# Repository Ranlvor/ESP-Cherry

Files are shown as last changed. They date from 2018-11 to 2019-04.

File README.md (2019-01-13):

# ESP-Cherry
Little board that connects 4 Cherry Switches and 4 LEDs to a Wemos D1 Mini Board

# Folder Structure:
* ESP-Cerry: KiCad Project of the Board
* gehaeuse: OpenSCAD Project for a 3D printed casing

# Parts
* U1: Wemos D1 Mini
* Switches SW1, SW2, SW3, SW4: CHERRY MX-Switches, choose to your liking
* Resistors R1, R2: Pull-Up-Resistors for SW3 and SW4, 1kΩ - 100kΩ should be fine
* LEDs D1, D2, D3, D4: LEDs to iluminate the Keykaps, choose to your liking.  Use LEDs which fit your switches. The switches I used fit 3mm LED's but some do not
* Resistors R3, R4, R5, R6: protective resistors for LEDs D1, D2, D3, D4: choose whatever fits your LEDs to be powered from 3.3V.

## Optional Parts:
* Add R7 = 4.7kΩ and U2 = DS18B20 for temperature mesurement

# Other
* Power the Wemos D1 via USB, it powers the rest of the board (or solder 3.3V or 5V directly to the Wemos)
* Mounting Holes fit M3 screws
* Mounting Holes Positions in mm from the lower left corner of the board:
  * 5.08, 20.32
  * 5.08, 40.64
  * 5.08, 58.42
  * 5.08, 78.74
  * 52.07, 7.62
  * 52.07, 78.74

# Software
* Use whatever can control IO pins
* I use Tasmota-Firmware with the following IO-settings:
  * Modul type: 18 Generic
  * D3 GPIO0: 15 Switch7
  * D4 GPIO2: 16 Switch8
  * D2 GPIO4: 14 Switch6
  * D1 GPIO5: 13 Switch5
  * D6 GPIO12: 22 Relay2
  * D7 GPIO13: 21 Relay1
  * D5 GPIO14: 23 Relay3
  * D0 GPIO16: 24 Relay4
  * otherwise: 00 None

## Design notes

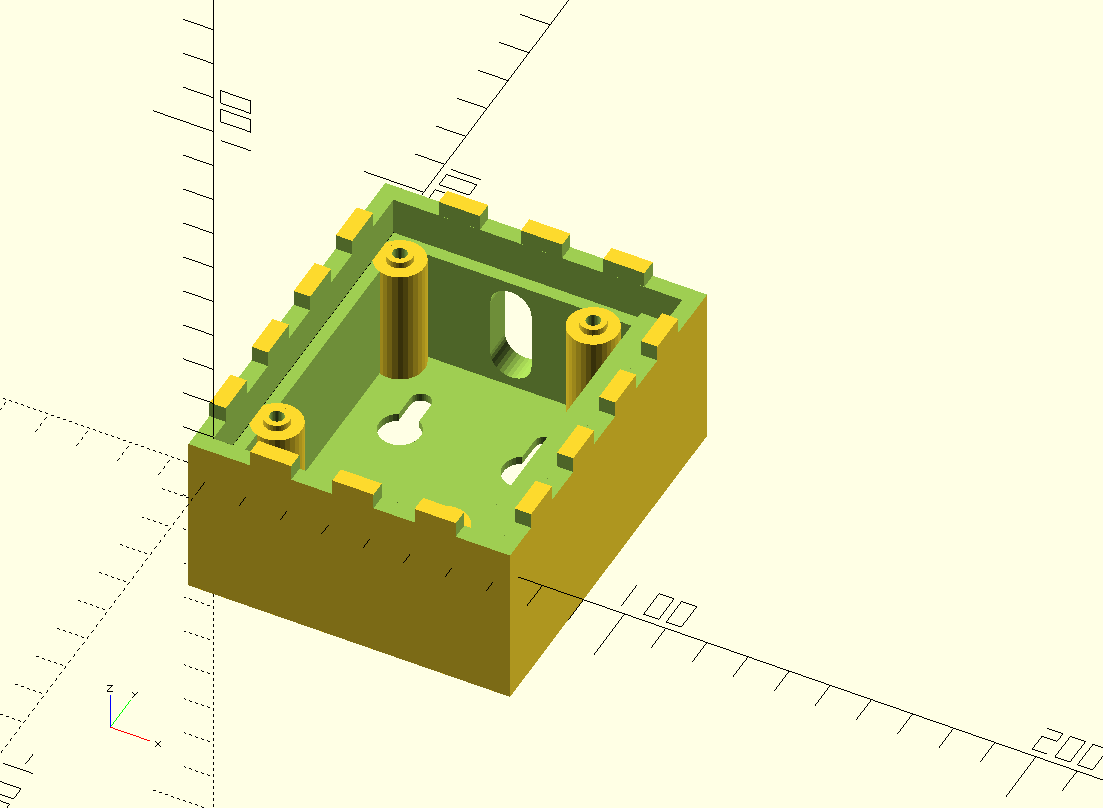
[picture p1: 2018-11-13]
gehaeuse/render.png

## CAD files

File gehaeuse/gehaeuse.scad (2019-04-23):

$fn = 32;
//unit = mm
boardTolerance = 0.5;
boardX = 59.69 + boardTolerance;
boardY = 85.09 + boardTolerance;
boardZ = 1.6;
overhang = 3;
delta = 0.02;
floorThickness = 2;
xExtraSpace = 10;
buttonToUserPannel = 12; //distance between top of board to top of gehaeuse
deckelDicke = 4;
wallUpper = deckelDicke;
//clearence = 30;
clearence = 25;

mountingPillarThickness = 6;
mountingNutDiameter = 4;
mountingNutScrewDiameter = 3;
renderMode = 1; //1 = 3D lower, 2 = 2D upper, 3 = 2D upper outline, 4 = 2D upper text
//color([0,1,0]) cube([boardX-delta, boardY-delta, boardZ-delta]);

tolerance = 0; //faster rendering
//tolerance = 2; //simpler testing
//tolerance = 0.3; //for final render

usbHoleThickness = 10;
usbHoleLength = 12;

mountingScrewDiameter = 6;
mountingScewHeadDiameter = 10;

module usbHole() {
    hull() {
        translate([-usbHoleLength/2,0,0]) cylinder(h=wallUpper+overhang+2*delta, d=usbHoleThickness);
        translate([+usbHoleLength/2,0,0]) cylinder(h=wallUpper+overhang+2*delta, d=usbHoleThickness);
    }
}

module mountingScrewHole() {
    hull() {
        translate([0,+mountingScewHeadDiameter/2,0]) cylinder(h=floorThickness+2*delta, d=mountingScrewDiameter);
        translate([0,-mountingScewHeadDiameter/2,0]) cylinder(h=floorThickness+2*delta, d=mountingScrewDiameter);
    }
    translate([0,-mountingScewHeadDiameter/2,0]) cylinder(h=floorThickness+2*delta, d=mountingScewHeadDiameter);
}

module mountingPiller(x,y) {
    translate([x,y,-clearence]) cylinder(h=clearence+delta, r=mountingPillarThickness);
    //translate([x,y,0]) cylinder(h=boardZ+2*delta, r=mountingHoleSize);
}

module mountingHole(x,y) {
    depth = 10;
    translate([x,y,-depth]) cylinder(h=depth+2*delta, d=mountingNutDiameter);
}
module upperPart() {   
    keyHoleSize = 19;
    textOffsetX = keyHoleSize/2 + 2;
    textOffsetY = 10/2;
    edgePatternSize = 10;
    if(renderMode != 4) {
    difference() {    
        color([0,1,0]) translate([-wallUpper-delta, -wallUpper-delta]) square(size = [boardX+2*wallUpper+xExtraSpace+2*delta, boardY+2*wallUpper+2*delta]);
        translate([17.78,12.70]) square(size = [keyHoleSize,keyHoleSize], center=true);
        translate([17.78,33.02]) square(size = [keyHoleSize,keyHoleSize], center=true);
        translate([17.78,53.34]) square(size = [keyHoleSize,keyHoleSize], center=true);
        translate([17.78,73.66]) square(size = [keyHoleSize,keyHoleSize], center=true);
        
        if(renderMode != 1) {
          translate([boardX+xExtraSpace/2, boardY-xExtraSpace/2]) circle(d=mountingNutScrewDiameter);
           translate([boardX+xExtraSpace/2, xExtraSpace/2]) circle(d=mountingNutScrewDiameter);
           translate([5.08+(boardTolerance/2), 40.64+(boardTolerance/2)]) circle(d=mountingNutScrewDiameter);
        }
        
        for(i = [1 : 2 : 8]) {
            translate([-wallUpper-delta, -wallUpper+i*edgePatternSize]) square(size = [deckelDicke+delta+tolerance,  edgePatternSize]);
            translate([boardX+xExtraSpace+2*delta-tolerance, -wallUpper+i*edgePatternSize]) square(size = [deckelDicke+delta+tolerance,  edgePatternSize]);
        }
        i = 1;
        for(i = [1.5 : 2 : 7]) {
          translate([-wallUpper-delta+i*edgePatternSize, -wallUpper-2*delta]) square(size = [edgePatternSize, deckelDicke+delta+tolerance]);
          translate([-wallUpper-delta+i*edgePatternSize, boardY+2*delta-tolerance]) square(size = [edgePatternSize, deckelDicke+delta+tolerance]);
        }
    }}
    if(renderMode != 3) {
      color([1,0,0]) translate([17.78+textOffsetX,12.70-textOffsetY]) text("Deko");
      color([1,0,0]) translate([17.78+textOffsetX,73.66-textOffsetY]) text("On");
      color([1,0,0]) translate([17.78+textOffsetX,53.34-textOffsetY]) text("Abort");
      color([1,0,0]) translate([17.78+textOffsetX,33.02-textOffsetY]) text("Off");
    }
}
/* //Prototype: Mounting Pillar
difference() {
mountingPiller(0,0);
translate([-20, -20, -52]) cube([50,50,50]);
mountingHole(0,0, "M3");
}
difference() {
mountingPiller(10,0);
translate([-20, -20, -52]) cube([50,50,50]);
mountingHole(10,0, "M4");
}
difference() {
mountingPiller(20,0);
translate([-20, -20, -52]) cube([50,50,50]);
mountingHole(20,0, "M5");
}
difference() {
mountingPiller(30,0);
translate([-20, -20, -52]) cube([60,60,50]);
mountingHole(30,0, "M6");
}*/

if(renderMode == 1) {
difference() {
union() {
difference() {
    mainCubeSizeX = boardX+2*wallUpper+xExtraSpace;
    mainCubeSizeY = boardY+2*wallUpper;
    mainCubeSizeZ = clearence+boardZ+floorThickness+buttonToUserPannel;
    
    translate([-wallUpper, -wallUpper, -clearence-floorThickness]) cube([mainCubeSizeX, mainCubeSizeY, mainCubeSizeZ]);
    translate([0, 0, 0]) cube([boardX, boardY, boardZ+delta+buttonToUserPannel]);
    translate([overhang, overhang, -clearence]) cube([boardX-1*overhang, boardY-2*overhang, clearence+boardZ]);
    translate([0,0, boardZ]) 
    difference() {
        cube([boardX+xExtraSpace-delta, boardY, buttonToUserPannel+2*delta]);
        translate([boardX-delta,-delta,0]) cube([xExtraSpace, xExtraSpace, buttonToUserPannel+3*delta]);
       translate([boardX-delta,boardY-xExtraSpace,0]) cube([xExtraSpace, xExtraSpace, buttonToUserPannel+3*delta]);
    }
    translate([0,0, buttonToUserPannel]) mountingHole(boardX+xExtraSpace/2,boardY-xExtraSpace/2);
    translate([0,0, buttonToUserPannel]) mountingHole(boardX+xExtraSpace/2,xExtraSpace/2);
    translate([0,0, boardZ + buttonToUserPannel - deckelDicke + delta]) minkowski(){
       linear_extrude(height = deckelDicke+delta) upperPart();
       sphere(tolerance);
    }
};

mountingPiller(5.08+(boardTolerance/2),20.32+(boardTolerance/2));

mountingPiller(5.08+(boardTolerance/2),40.64+(boardTolerance/2));
//mountingHole(5.08,40.64);
//mountingHole(5.08,58.42);
mountingPiller(5.08+(boardTolerance/2),78.74+(boardTolerance/2));
mountingPiller(52.07+(boardTolerance/2),7.62+(boardTolerance/2));
difference() {
    union() {
        mountingPiller(52.07+(boardTolerance/2),78.74+(boardTolerance/2));
        translate([52.07+(boardTolerance/2),78.74+(boardTolerance/2)-mountingPillarThickness,-clearence]) cube([mountingPillarThickness+4,2*mountingPillarThickness,clearence]);
    }
    translate([52.07+(boardTolerance/2),78.74+(boardTolerance/2)-10,-28]) rotate([45,0,0]) translate([-10,0,-100]) cube([20,20,200]);
}
}

mountingHole(5.08+(boardTolerance/2),20.32+(boardTolerance/2));
mountingHole(5.08+(boardTolerance/2),40.64+(boardTolerance/2));
mountingHole(5.08+(boardTolerance/2),78.74+(boardTolerance/2));
mountingHole(52.07+(boardTolerance/2),7.62+(boardTolerance/2));
mountingHole(52.07+(boardTolerance/2),78.74+(boardTolerance/2));

translate([boardX/2,boardY+wallUpper+delta,-13]) rotate([90,90,0]) usbHole();

translate([boardX/4, 3*boardY/4,-clearence-floorThickness-delta]) mountingScrewHole();
translate([3*boardX/4, 3*boardY/4,-clearence-floorThickness-delta]) mountingScrewHole();

//Prototype: deckel
//translate([-500,-500,-995]) cube([1000, 1000, 1000]);

//Prototype: Mounting the Board
//*
//translate([-500,-500,2*boardZ]) cube([1000, 1000, 1000]);
//translate([-500,-500,-1000-boardZ]) cube([1000, 1000, 1000]); /* */
};


} else {
    upperPart();
}

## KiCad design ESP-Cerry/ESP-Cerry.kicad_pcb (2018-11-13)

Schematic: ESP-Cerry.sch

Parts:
D1, D2, D3, D4: LED; LED_D3.0mm
MH1, MH2, MH3, MH4, MH5, MH6: MountingHole; MountingHole_3.2mm_M3
R1, R2: 10k; R_0805_2012Metric_Pad1.15x1.40mm_HandSolder
R3, R4, R5, R6: R; R_0805_2012Metric_Pad1.15x1.40mm_HandSolder
R7: 4.7k; R_0805_2012Metric_Pad1.15x1.40mm_HandSolder
SW1, SW2, SW3, SW4: SW_Push; SW_Cherry_MX1A_1.00u_PCB
U1: WeMos_mini; D1_mini_board
U2: DS18B20; TO-92_Inline

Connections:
+3V3: R1.1, R2.1, R7.2, U1.16, U2.3 (VDD)
GND: R3.1, R4.1, R5.1, R6.1, SW1.1, SW2.1, SW3.1, SW4.1, U1.2, U2.1 (GND)
unnamed: D1.1, R3.2
unnamed: D1.2, U1.14
unnamed: D2.1, R4.2
unnamed: D2.2, U1.13
unnamed: D3.1, R5.2
unnamed: D3.2, U1.12
unnamed: D4.1, R6.2
unnamed: D4.2, U1.11
unnamed: R1.2, SW3.2, U1.5
unnamed: R2.2, SW4.2, U1.6
unnamed: R7.1, U1.8, U2.2 (DQ)
unnamed: SW1.2, U1.3
unnamed: SW2.2, U1.4

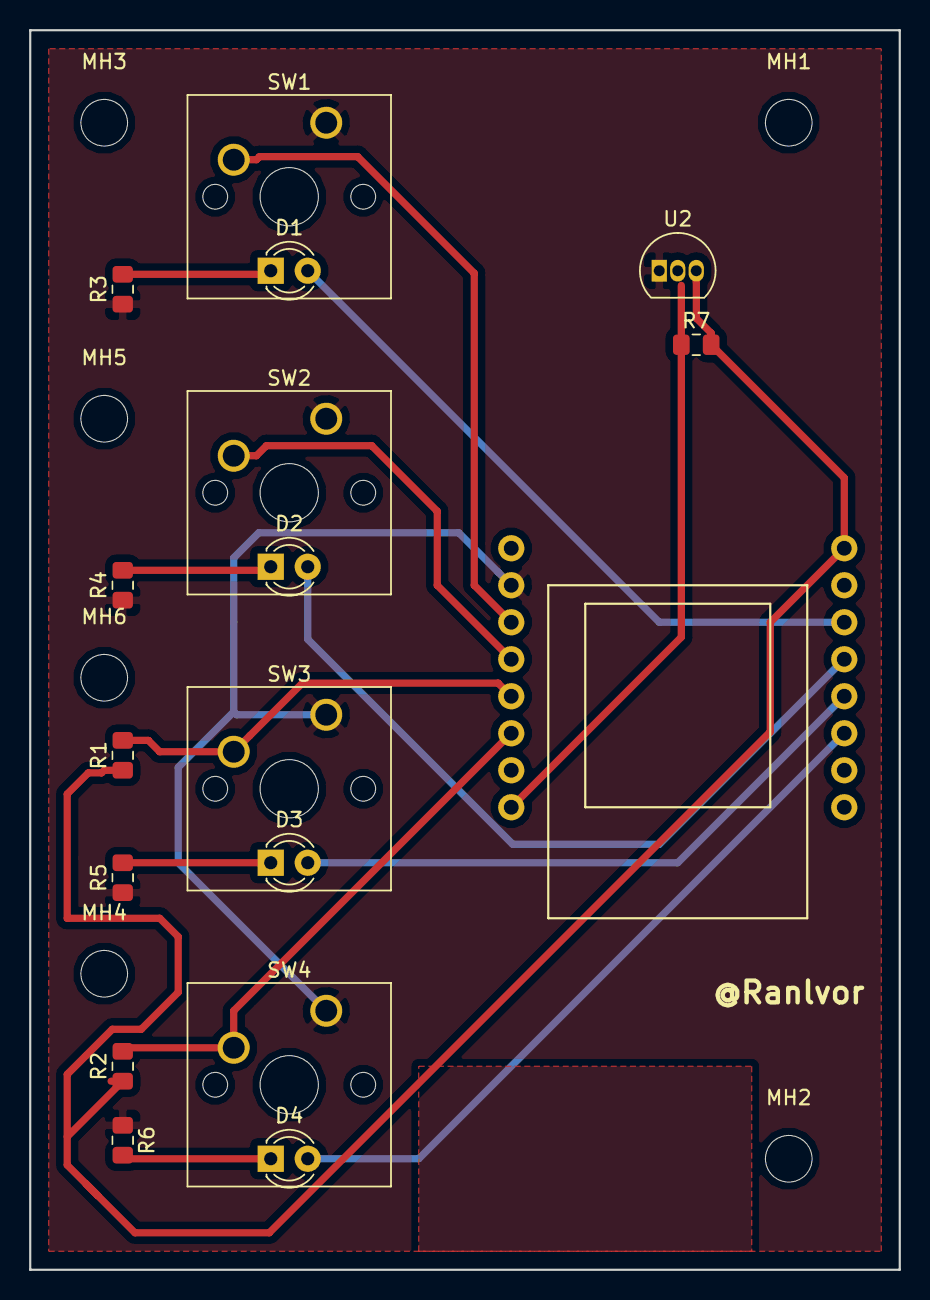
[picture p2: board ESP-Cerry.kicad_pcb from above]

Board: 2 copper layers, 59.7 x 85.1 mm, 23 parts (1 on the bottom side), 15 nets.

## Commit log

2019-01-13 README: add LED Voltage
2019-04-23 redo all the mounting
    - Add mounting screws for front plate
    - Use M3 mold in nuts to fasten front plate and main board
    [gehaeuse.scad]
2019-04-23 redo stuff
    - changed the tolerance-stuff to reduce artifacts
    - more room for USB connector
    - dedicated mounting pillar for front plate
    [gehaeuse.scad]
